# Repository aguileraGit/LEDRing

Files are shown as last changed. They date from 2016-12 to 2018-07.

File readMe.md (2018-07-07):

## Update
As best as I can remember, the mold needs to be solid. The silicon-ish material didn't stick well. And apparently I've decided to add a motor driver. I think the PCB is all working (v1.2). I really want to change out the LEDs so they're cheaper.

## READ ME
LED Ring (needs a better name) is an Arduino based platform. It contains a ring of LEDs, accelerometer, Atmel 328p, FTDI, USB (IP68), and debug LED. In the future the device will be encased in silicon-ish type material making the device IP68. Yes, you'll be able to dunk it in water.

## Hardware
A few minor updates need to be done to the HW. Mainly a capacitor to keep the FTDI from resetting and preventing uploads from Arduino IDE. I think there's a capacitor that needs a different footprint.

## Software
Current SW is interruptTest.ino. I really need to create a library to hide a lot of stuff (define DEBUG_LED for example).

Thanks to all who have created libraries and saved me countless hours. Mainly MMA8452 and NeoPixels!

## Mold
Four part mold. Two parts create the mold. The third holds a magnet that interns holds the PCB steady while pouring the silicon. The forth part contains a "nub" to prevent the PCB from wiggling around. This is meant to be printed at 0.1mm resolution. It needs to be glued on to the rest of the mold. The rest of the parts can be printed at 0.2mm.
- Bluesil V-249A/B.
- Hardness: 67A (Fitbit band has a hardness of 60)
- https://www.freemansupply.com/products/mold-making-silicone-rubber/bluestar-addition-cure-silicone-rubber/v-249-mold-making-silicone-rubber-heat-cure
 - Need to upload the 3d mold models.
 - Need to upload print settings.

#### Old references - Might not even be using some of these.
https://github.com/MajenkoLibraries/Average
https://github.com/rocketscream/Low-Power
https://github.com/adafruit/Adafruit_NeoPixel
https://github.com/akupila/Arduino-MMA8452

#### Or these
http://www.engblaze.com/hush-little-microprocessor-avr-and-arduino-sleep-mode-basics/
http://rubenlaguna.com/wp/2008/10/15/arduino-sleep-mode-waking-up-when-receiving-data-on-the-usart/
https://www.arduino.cc/en/Tutorial/SerialEvent
http://donalmorrissey.blogspot.com/2011/11/sleeping-arduino-part-4-wake-up-via.html

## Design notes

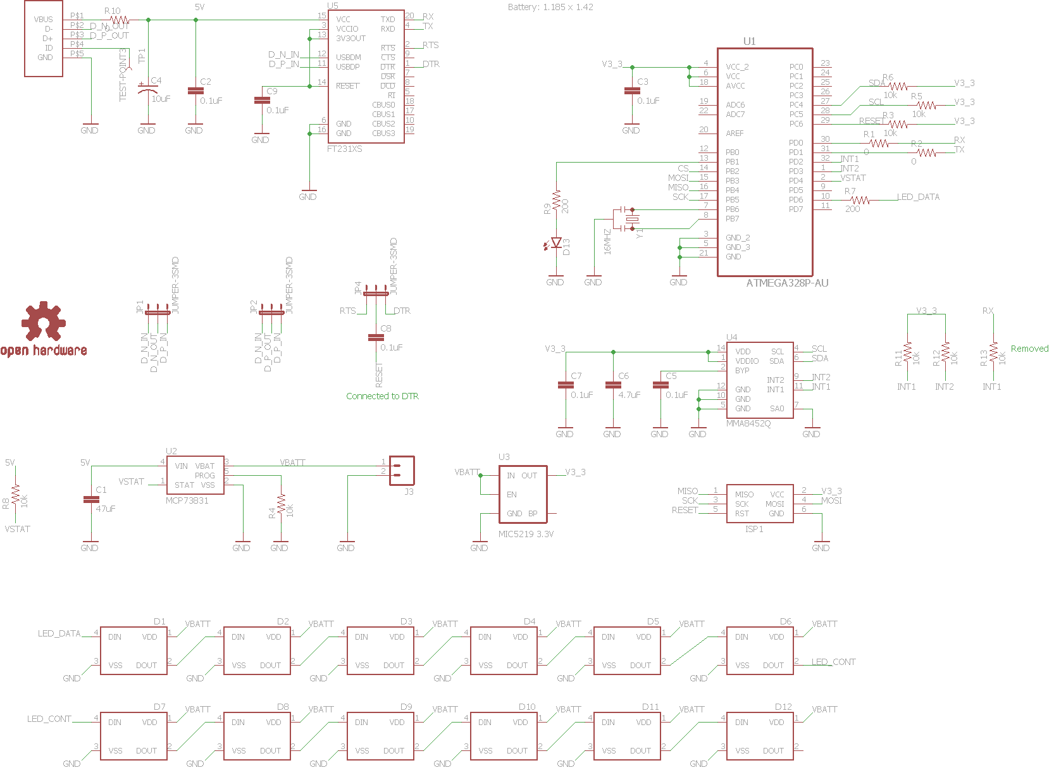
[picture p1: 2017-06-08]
ledRing.png

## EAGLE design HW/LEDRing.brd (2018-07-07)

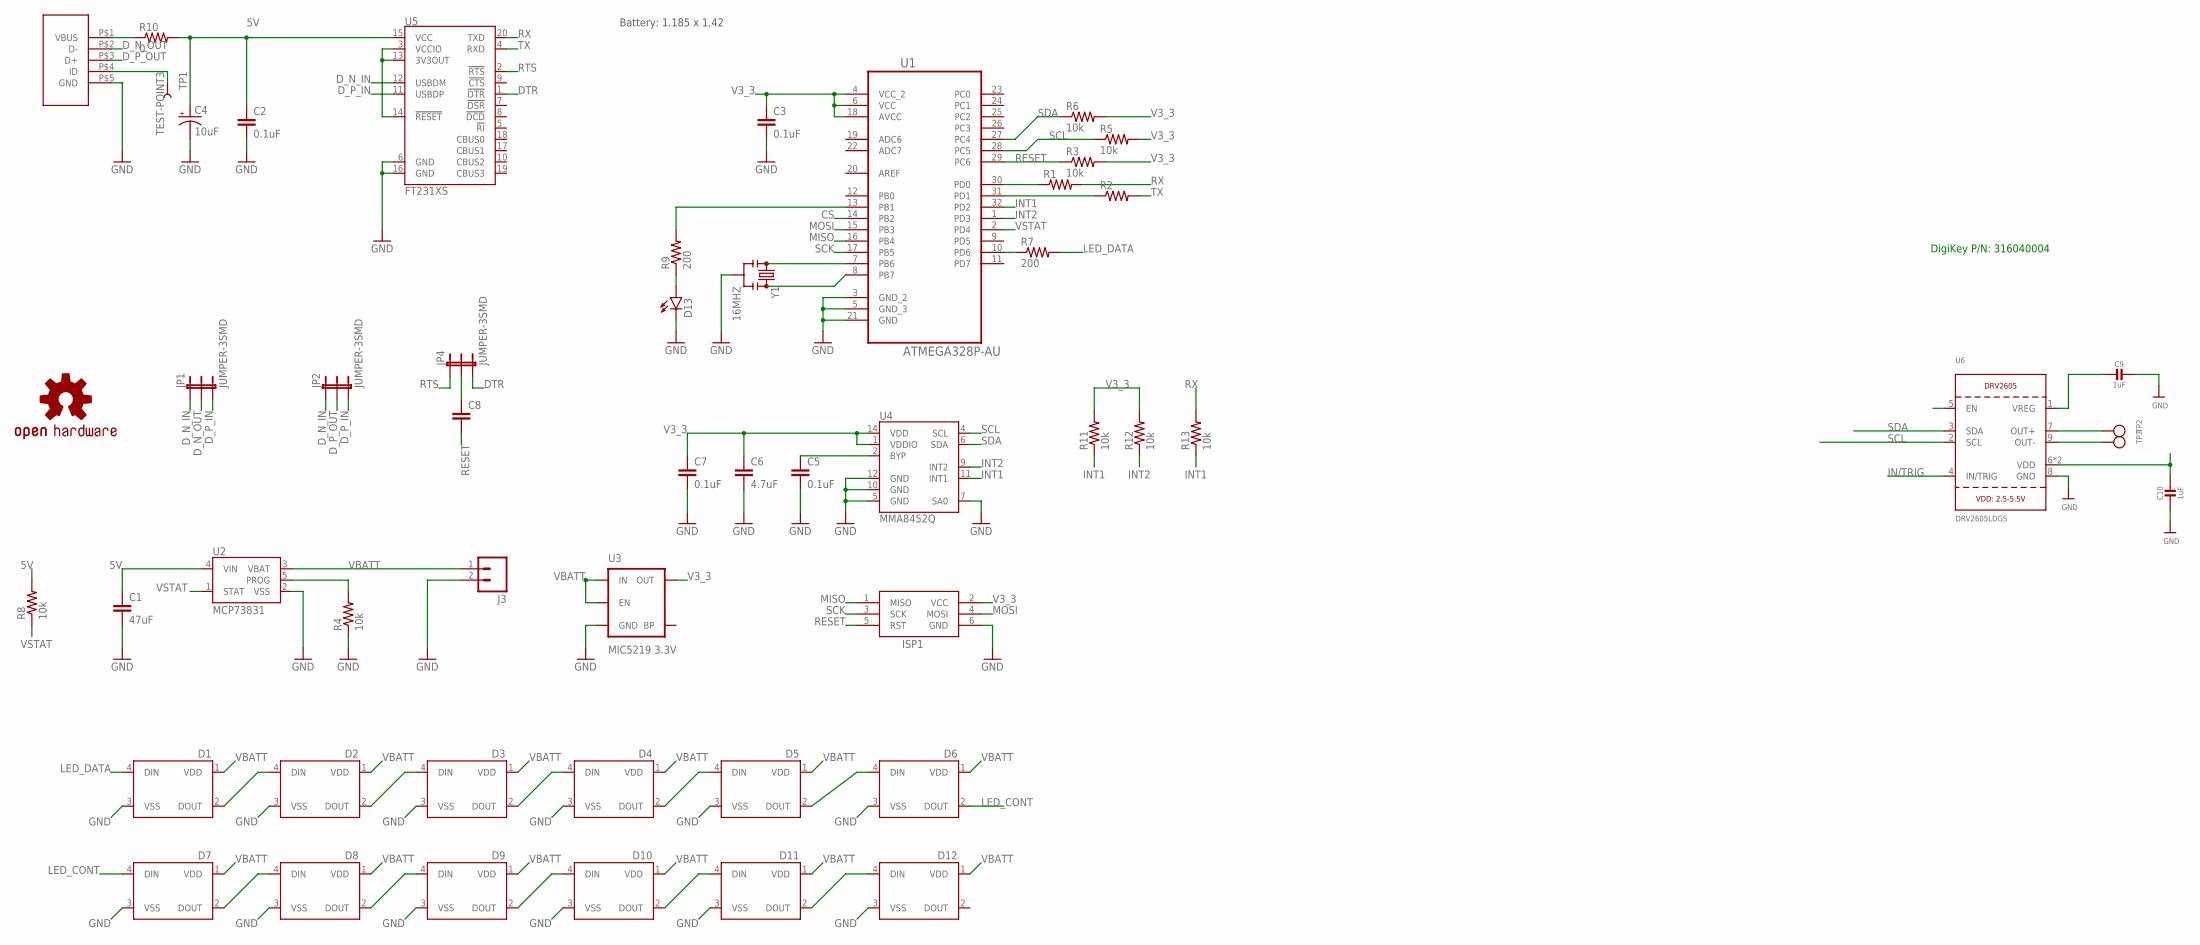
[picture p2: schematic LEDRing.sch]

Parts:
C1: 47uF; 0603-CAP
C2, C3, C5, C7: 0.1uF; 0603-CAP
C4: 10uF; 0603-POL
C6: 4.7uF; 0603-CAP
C8: CAP0603-CAP; 0603-CAP
C9, C10: 1uF; 0805-NO
D1, D2, D3, D4, D5, D6, D7, D8, D9, D10, D11, D12: WS2812B
D13: LED0603; LED-0603
ISP1: AVRISP-BOX
J3: M02PTH; 1X02
JP1, JP2, JP4: JUMPER-3SMD; SJ_3
LOGO1: OSHW-LOGOMINI; OSHW-LOGO-MINI
R1, R2: RESISTOR0603-RES; 0603-RES
R3, R4, R5, R6, R8, R11, R12, R13: 10k; 0603-RES
R7, R9: 200; 0603-RES
R10: 0; 0603-RES
TP1: TEST-POINT3; PAD.03X.03
TP2, TP3: TESTPOINTPAD2MM; TESTPOINT_PAD_2MM
U1: ATMEGA328P-AU; QFP80P900X900X120-32N
U2: MCP73831; SOT23-5
U3: MIC5219 3.3V; SOT23-5
U4: MMA8452Q; QFN-16_0.5MM
U5: FT231XS; SSOP20_L
U6: DRV2605LDGS; PSOP10
U$1: TE_USB_A121025CT
Y1: 16MHZ; RESONATOR-SMD

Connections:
5V: C1.1, C2.1, C4.A (+), R8.2, R10.2, U2.4 (VIN), U5.15 (VCC)
CS: U1.14 (PB2)
DTR: JP4.3, U5.1 (!DTR)
D_N_IN: JP1.1, JP2.1, U5.12 (USBDM)
D_N_OUT: JP1.2, U$1.P$2 (D-)
D_P_IN: JP1.3, JP2.3, U5.11 (USBDP)
D_P_OUT: JP2.2, U$1.P$3 (D+)
GND: C1.2, C2.2, C3.2, C4.K (-), C5.2, C6.2, C7.2, C9.1, C10.2, D1.3 (VSS), D2.3 (VSS), D3.3 (VSS), D4.3 (VSS), D5.3 (VSS), D6.3 (VSS), D7.3 (VSS), D8.3 (VSS), D9.3 (VSS), D10.3 (VSS), D11.3 (VSS), D12.3 (VSS), D13.C, ISP1.6 (GND), J3.2, R4.1, U1.3 (GND_2), U1.5 (GND_3), U1.21 (GND), U2.2 (VSS), U3.2 (GND), U4.5 (GND), U4.7 (SA0), U4.10 (GND), U4.12 (GND), U5.6 (GND), U5.16 (GND), U6.8 (GND), U$1.P$5 (GND), Y1.2
IN/TRIG: U6.4 (IN/TRIG)
INT1: R11.1, R13.1, U1.32 (PD2), U4.11 (INT1)
INT2: R12.1, U1.1 (PD3), U4.9 (INT2)
LED_CONT: D6.2 (DOUT), D7.4 (DIN)
LED_DATA: D1.4 (DIN), R7.2
MISO: ISP1.1 (MISO), U1.16 (PB4)
MOSI: ISP1.4 (MOSI), U1.15 (PB3)
unnamed: R1.1, U1.30 (PD0)
unnamed: R2.1, U1.31 (PD1)
unnamed: C5.1, U4.2 (BYP)
unnamed: R10.1, U$1.P$1 (VBUS)
unnamed: U5.3 (VCCIO), U5.13 (3V3OUT), U5.14 (!RESET)
unnamed: U1.8 (PB7), Y1.3
unnamed: U1.7 (PB6), Y1.1
unnamed: R4.2, U2.5 (PROG)
unnamed: R7.1, U1.10 (PD6)
unnamed: D1.2 (DOUT), D2.4 (DIN)
unnamed: D2.2 (DOUT), D3.4 (DIN)
unnamed: D3.2 (DOUT), D4.4 (DIN)
unnamed: D4.2 (DOUT), D5.4 (DIN)
unnamed: D5.2 (DOUT), D6.4 (DIN)
unnamed: D7.2 (DOUT), D8.4 (DIN)
unnamed: D8.2 (DOUT), D9.4 (DIN)
unnamed: D9.2 (DOUT), D10.4 (DIN)
unnamed: D10.2 (DOUT), D11.4 (DIN)
unnamed: D11.2 (DOUT), D12.4 (DIN)
unnamed: C9.2, U6.1 (VREG)
unnamed: R9.2, U1.13 (PB1)
unnamed: D13.A, R9.1
unnamed: TP1.P$1, U$1.P$4 (ID)
unnamed: C10.1, U6.6 (VDD), U6.10 (VDD)
OUT+: TP2.P$1, U6.7 (OUT+)
OUT-: TP3.P$1, U6.9 (OUT-)
RESET: C8.2, ISP1.5 (RST), R3.1, U1.29 (PC6)
RTS: JP4.1, U5.2 (!RTS)
RTS_OR_DTR: C8.1, JP4.2
RX: R1.2, R13.2, U5.20 (TXD)
SCK: ISP1.3 (SCK), U1.17 (PB5)
SCL: R5.1, U1.28 (PC5), U4.4 (SCL), U6.2 (SCL)
SDA: R6.1, U1.27 (PC4), U4.6 (SDA), U6.3 (SDA)
TX: R2.2, U5.4 (RXD)
V3_3: C3.1, C6.1, C7.1, ISP1.2 (VCC), R3.2, R5.2, R6.2, R11.2, R12.2, U1.4 (VCC_2), U1.6 (VCC), U1.18 (AVCC), U3.5 (OUT), U4.1 (VDDIO), U4.14 (VDD)
VBATT: D1.1 (VDD), D2.1 (VDD), D3.1 (VDD), D4.1 (VDD), D5.1 (VDD), D6.1 (VDD), D7.1 (VDD), D8.1 (VDD), D9.1 (VDD), D10.1 (VDD), D11.1 (VDD), D12.1 (VDD), J3.1, U2.3 (VBAT), U3.1 (IN), U3.3 (EN)
VSTAT: R8.1, U1.2 (PD4), U2.1 (STAT)

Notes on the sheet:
Battery: 1.185 x 1.42
DigiKey P/N: 316040004

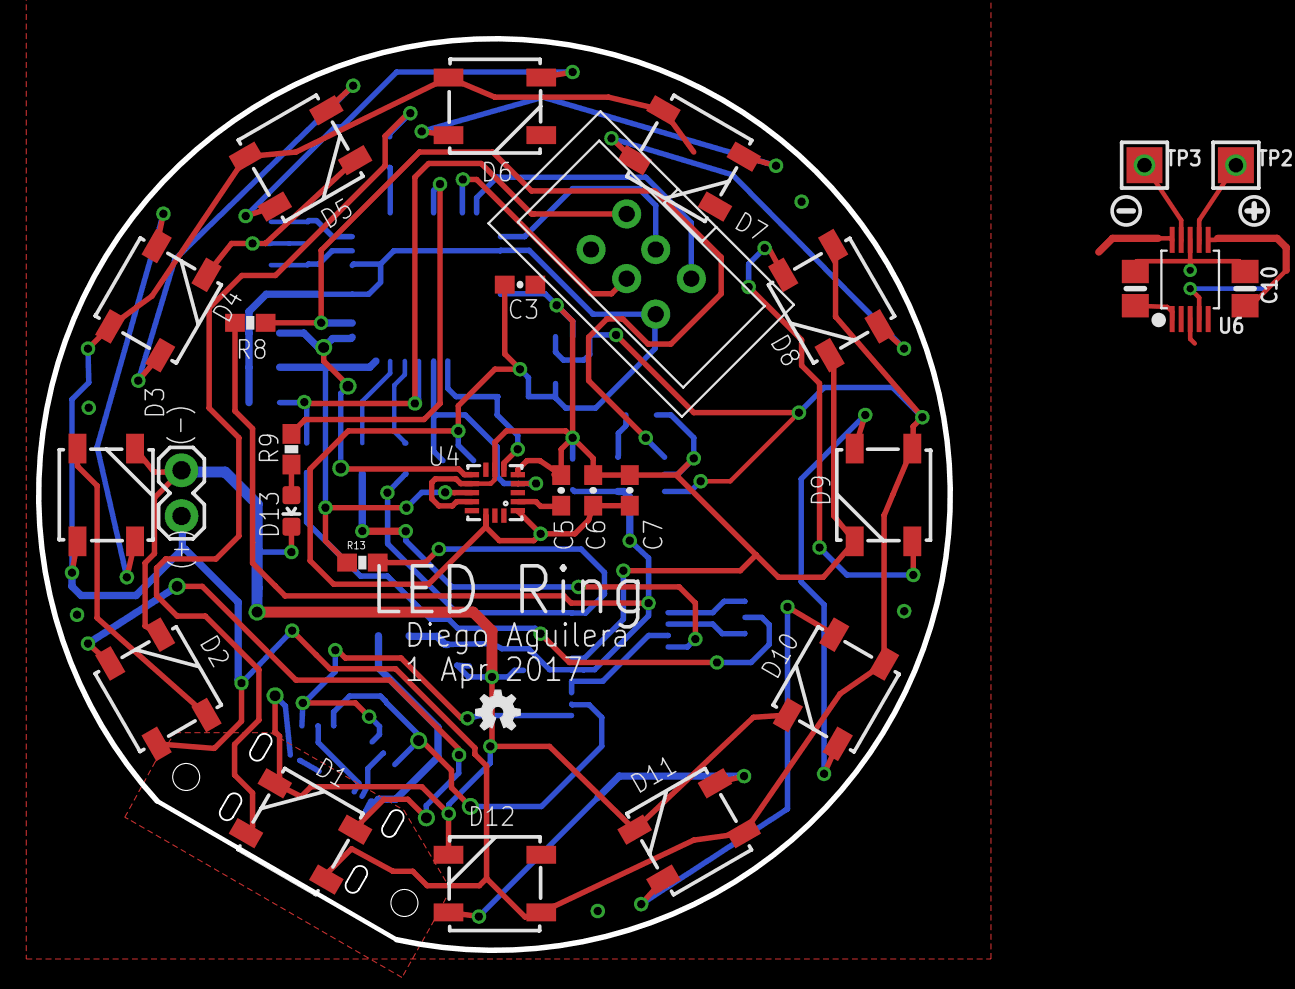
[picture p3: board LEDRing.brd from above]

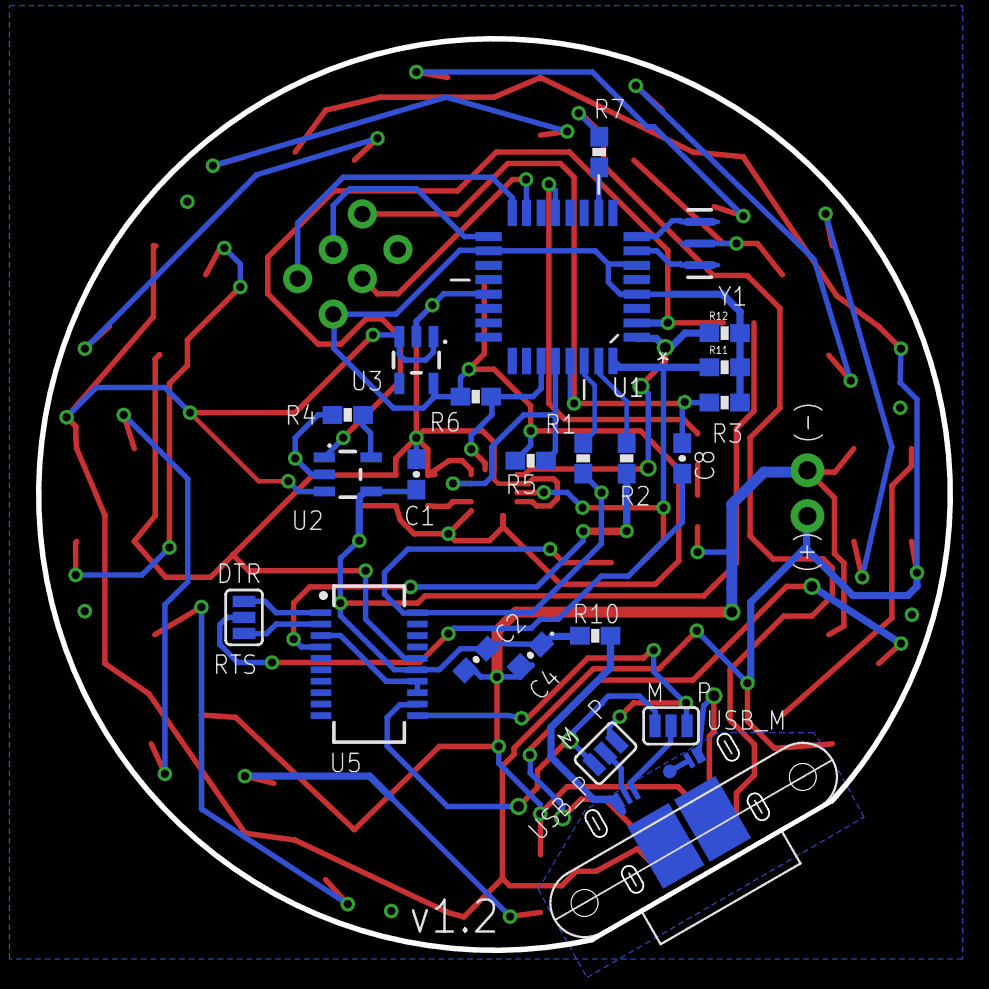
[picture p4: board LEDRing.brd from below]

Board: 2 copper layers, 50.6 x 50.6 mm, 55 parts (24 on the bottom side), 50 nets.

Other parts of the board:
U$5: SYMBOL_PLUS
U$13: SYMBOL_MINUS

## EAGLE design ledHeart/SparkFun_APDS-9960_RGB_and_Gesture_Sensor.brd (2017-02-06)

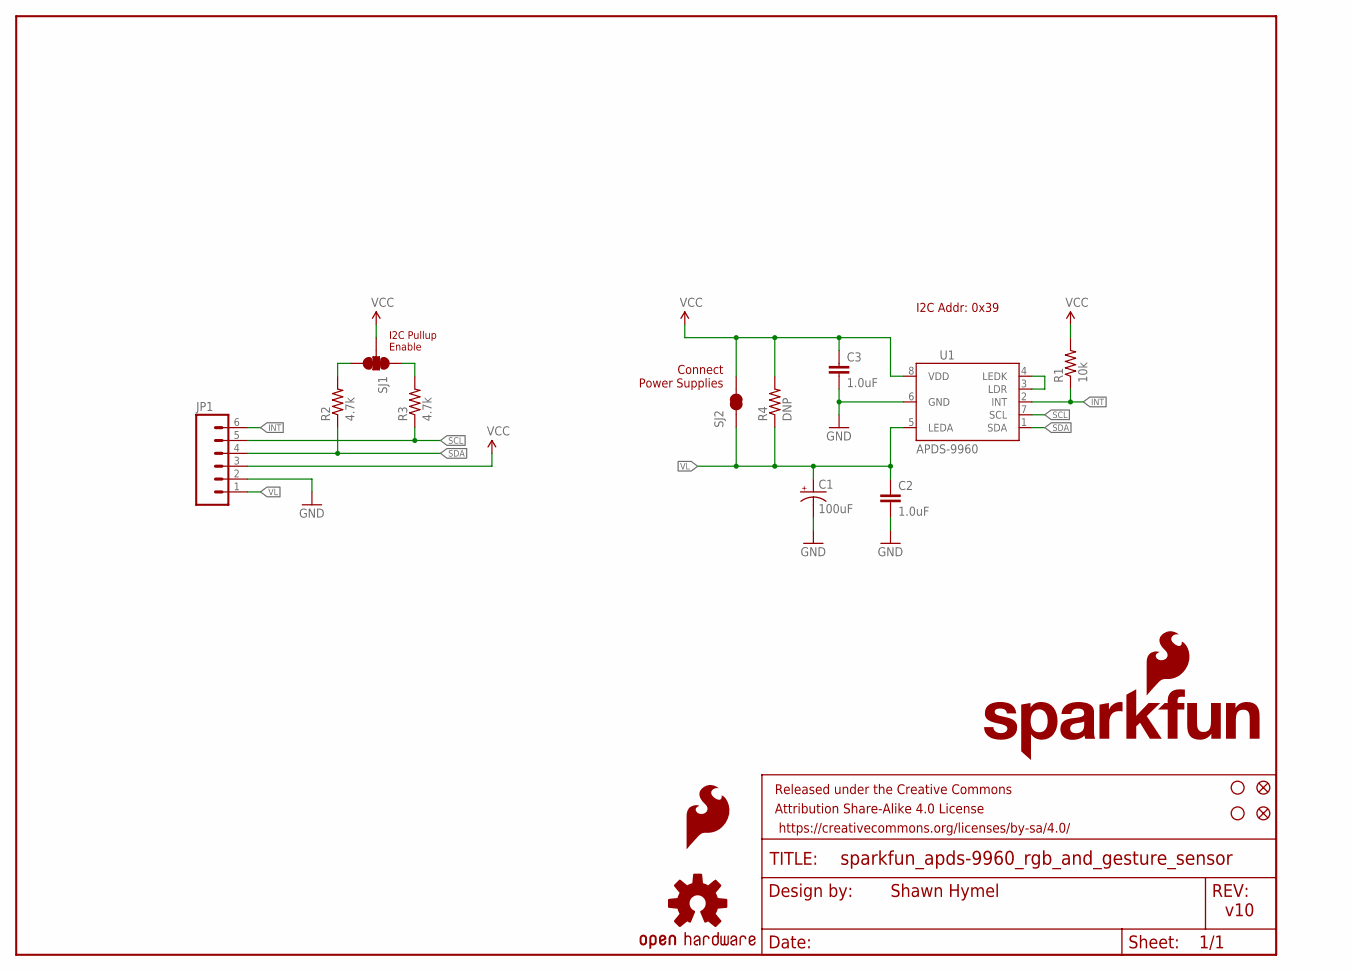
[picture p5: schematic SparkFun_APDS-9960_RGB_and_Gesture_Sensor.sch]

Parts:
C1: 100uF; EIA7343
C2, C3: 1.0uF; 0603-CAP
FID1, FID2: FIDUCIAL1X2; FIDUCIAL-1X2
FRAME1: FRAME-LETTER; CREATIVE_COMMONS
JP1: M06SIP; 1X06
LOGO1: SFE_LOGO_FLAME.1_INCH; SFE_LOGO_FLAME_.1
LOGO2: OSHW-LOGOS; OSHW-LOGO-S
R1: 10k; 0603-RES
R2, R3: 4.7k; 0603
R4: DNP; 0603-RES
SJ1: SOLDERJUMPER_2WAYPASTE1&2&3; SJ_3_PASTE1&2&3
SJ2: SOLDERJUMPERNC; SJ_2S
STANDOFF1, STANDOFF2: STAND-OFF
U1: APDS-9960
U$1: SFE_LOGO_NAME_FLAME.1_INCH; SFE_LOGO_NAME_FLAME_.1

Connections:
GND: C1.C (-), C2.2, C3.2, JP1.2, U1.6 (GND)
INT: JP1.6, R1.1, U1.2 (INT)
unnamed: R2.2, SJ1.3
unnamed: R3.2, SJ1.1
unnamed: U1.3 (LDR), U1.4 (LEDK)
SCL: JP1.5, R3.1, U1.7 (SCL)
SDA: JP1.4, R2.1, U1.1 (SDA)
VCC: C3.1, JP1.3, R1.2, R4.2, SJ1.2, SJ2.2, U1.8 (VDD)
VL: C1.A (+), C2.1, JP1.1, R4.1, SJ2.1, U1.5 (LEDA)

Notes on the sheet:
v10
Shawn Hymel
I2C Addr: 0x39
I2C Pullup Enable
Connect Power Supplies

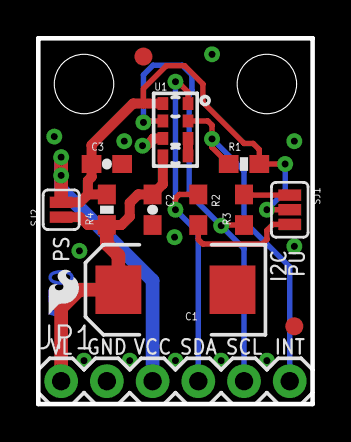
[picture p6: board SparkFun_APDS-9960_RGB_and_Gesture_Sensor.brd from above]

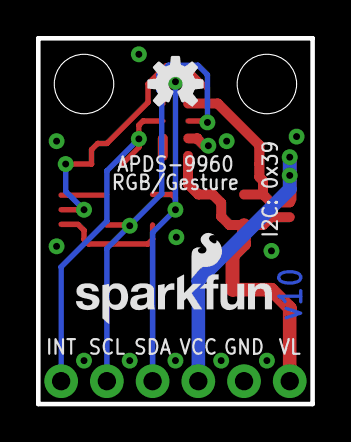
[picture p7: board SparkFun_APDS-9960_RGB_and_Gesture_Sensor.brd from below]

Board: 2 copper layers, 15.2 x 20.3 mm, 19 parts (2 on the bottom side), 9 nets.

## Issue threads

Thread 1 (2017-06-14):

Try this

aguileraGit, 2017-06-14:
#include <TimerOne.h>
#include <Wire.h>
#include <MMA8452.h>
#include <MMA8452Reg.h>
#include <Adafruit_NeoPixel.h>
#include <LowPower.h>
#include <avr/power.h>

https://www.amazon.com/Inkbird-Temperature-ITC-100VH-40A-SSR/dp/B00ADHNSGI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

//Debug LED
#define DEBUG_LED  9

//NeoPixels
#define PIXEL_PIN  6
#define PIXEL_COUNT 12

//System
MMA8452 accelerometer;
Adafruit_NeoPixel strip = Adafruit_NeoPixel(PIXEL_COUNT, PIXEL_PIN, NEO_GRB);
volatile bool interrupt;
unsigned long timerCount;
#define SHUTDOWN  5000  //Shutdown - 1000ms = 1s

//App specific Led
volatile bool updateBlinkLed;
volatile bool ledBlink;
volatile bool updateAllLeds;
volatile int updateAllCount;
volatile int currentPixel;

volatile int ledNumAtTap;

volatile int ledNum;
volatile int randLed;

//Sleep
bool sleepEnabled;
bool sleepingZZZ;
bool activity;
unsigned long activityCount;

void setup() {
  //Enable Debug LED
  pinMode(DEBUG_LED, OUTPUT);

  //Start i2c (Wire) for accelerometer
  Wire.begin();

  bool initialized = accelerometer.init();

  if (initialized) {
    accelerometer.setDataRate(MMA_400hz);
    accelerometer.setRange(MMA_RANGE_2G);

    accelerometer.enableSingleTapDetector(MMA_X + MMA_Y + MMA_Z);
    accelerometer.enableDoubleTapDetector(MMA_X + MMA_Y + MMA_Z, 0x33, 0xBB);
    accelerometer.setTapThreshold(0x20, 0x20, 0x20);

    accelerometer.setInterruptsEnabled(MMA_TAP);
    accelerometer.configureInterrupts(false, false);
    accelerometer.setInterruptPins(false, false, false, true, false, false);

    attachInterrupt(0, accelerometerInterruptHandler, FALLING);
  }

  //Timer
  Timer1.initialize(1000); //1000ns = 1ms
  Timer1.attachInterrupt(oneMsTimer);

  //Neopixels
  strip.begin();
  strip.show();

  //App specific
  interrupt = false;
  sleepEnabled = true;
  ledBlink = false;
  activity = false;
  activityCount = 0;
  sleepingZZZ = false;

  updateAllCount = 0;
  currentPixel = 0;

  randomSeed(analogRead(0));
  randLed = random(PIXEL_COUNT);
}

void loop() {

  if (!sleepingZZZ) {

    if (interrupt) {
      interrupt = false;

      Timer1.stop();

      bool singleTap, doubleTap;
      bool x, y, z;
      bool negX, negY, negZ;

      //Clear it by reading from it. Duh!
      accelerometer.getTapDetails(&singleTap, &doubleTap, &x, &y, &z, &negX, &negY, &negZ);

      if (singleTap) {
        //Clear all
        for (int j = 0; j < PIXEL_COUNT; j++) {
          strip.setPixelColor(j, strip.Color(0, 0, 0));
          strip.show();
        }

        if (ledNumAtTap == randLed) {
          strip.setPixelColor(ledNumAtTap, strip.Color(0, 32, 0));
          strip.show();
        } else {
          strip.setPixelColor(ledNumAtTap, strip.Color(32, 0, 0));
          strip.show();
        }

        delay(800);
      }

      //Get new random LED
      randLed = random(PIXEL_COUNT);

    //Resume interrupt and timer operations
    Timer1.resume();

    } //End interrupt

    if (updateBlinkLed) {
      Timer1.stop();
      ledBlink = !ledBlink;

      //Clear all
      for (int j = 0; j < PIXEL_COUNT; j++) {
        strip.setPixelColor(j, strip.Color(0, 0, 0));
        strip.show();
      }

      for (int i = 0; i < PIXEL_COUNT; i++) {
        if (i == currentPixel) {
          strip.setPixelColor(currentPixel, strip.Color(16, 16, 16));
        } else if (i == randLed) {
          if (ledBlink) {
            strip.setPixelColor(randLed, strip.Color(0, 0, 32));
          } else {
            strip.setPixelColor(randLed, strip.Color(0, 0, 0));
          }
        } else {
          strip.setPixelColor(i, strip.Color(0, 0, 0));
        }
        strip.show();
      }

      //Blinking on the target LED is faster than the other LEDs - Control the rate of all the LEDs here.
      updateAllCount++;
      if (updateAllCount >= 2) {
        updateAllCount = 0;

        currentPixel++;

        if (currentPixel >= PIXEL_COUNT) {
          currentPixel = 0;
        }

      }

      updateBlinkLed = false;
      Timer1.resume();
    }

    //Sleep - power savings
    if (sleepEnabled) {
      sleepFn();
    }

  }//Sleeping

}

void accelerometerInterruptHandler() {
  interrupt = true;
  activity = true;
  ledNumAtTap = currentPixel;
  //sleepingZZZ = false;
}

void oneMsTimer() {

  //Update every 1ms
  timerCount++;

  //Update every 100ms
  if (timerCount % 100 == 0) {
    ;
  }

  //Update every 50ms
  if (timerCount % 20 == 0) {
    updateBlinkLed = true;
  }

  //-------- Track no activity --------//

  /*if (activity == false) {
    activityCount++;
  } else {
    activityCount = 0;
    activity = false;
  }
  */

  //-------- Shut Down --------//
  if (activityCount == SHUTDOWN) {
    activityCount = 0;

    //Turn off Debug LED
    //digitalWrite(DEBUG_LED, HIGH);

    //Turn off Pixels
    for (int j = 0; j < PIXEL_COUNT; j++) {
      strip.setPixelColor(j, strip.Color(0, 0, 0));
      strip.show();
    }

    //sleepingZZZ = true;
    //Call sleep function.
    //while (sleepingZZZ) {
    //sleepFn();
    //}

  }
}

void sleepFn() {
  LowPower.idle(SLEEP_15MS, ADC_OFF, TIMER2_OFF, TIMER1_ON, TIMER0_OFF, SPI_OFF, USART0_ON, TWI_ON);
}

Closed 2017-06-16.

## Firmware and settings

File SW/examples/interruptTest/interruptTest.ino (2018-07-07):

#include <TimerOne.h>
#include <Wire.h>
#include <MMA8452.h>
#include <MMA8452Reg.h>
#include <Adafruit_NeoPixel.h>
#include <LowPower.h>
#include <avr/power.h>

//Debug LED
#define DEBUG_LED  9

//NeoPixels
#define PIXEL_PIN  6
#define PIXEL_COUNT 12

//System
MMA8452 accelerometer;
Adafruit_NeoPixel strip = Adafruit_NeoPixel(PIXEL_COUNT, PIXEL_PIN, NEO_GRB);
volatile bool interrupt;
unsigned long timerCount;
#define SHUTDOWN  30000  //Shutdown - 1000ms = 1s
volatile bool shutDown;

//App specific Led
volatile bool updateBlinkLed;
volatile bool ledBlink;
volatile bool updateAllLeds;
volatile int updateAllCount;
volatile int currentPixel;

volatile int ledNumAtTap;
volatile int ledNum;
volatile int randLed;

#define GAME_SPEED_SLOW  80 
#define GAME_SPEED_FAST  20
#define GAME_SPEED       GAME_SPEED_SLOW

//Sleep
bool sleepEnabled;
bool activity;
unsigned long activityCount;


void setup() {
  
  //Enable Debug LED
  pinMode(DEBUG_LED, OUTPUT);

  //Start i2c (Wire) for accelerometer
  Wire.begin();

  bool initialized = accelerometer.init();

  if (initialized) {
    accelerometer.setDataRate(MMA_400hz);
    accelerometer.setRange(MMA_RANGE_2G);

    accelerometer.enableSingleTapDetector(MMA_X + MMA_Y + MMA_Z);
    accelerometer.enableDoubleTapDetector(MMA_X + MMA_Y + MMA_Z, 0x33, 0xBB);
    accelerometer.setTapThreshold(0x20, 0x20, 0x20);

    accelerometer.setInterruptsEnabled(MMA_TAP);
    accelerometer.configureInterrupts(false, false);
    accelerometer.setInterruptPins(false, false, false, true, false, false);

    attachInterrupt(0, accelerometerInterruptHandler, FALLING);
  }

  //Timer
  Timer1.initialize(1000); //1000ns = 1ms
  Timer1.attachInterrupt(oneMsTimer);

  //Neopixels
  strip.begin();
  strip.show();

  //App specific
  interrupt = false;
  sleepEnabled = true;
  ledBlink = false;
  activity = false;
  activityCount = 0;
  shutDown = false;

  updateAllCount = 0;
  currentPixel = 0;

  randomSeed(analogRead(0));
  randLed = random(PIXEL_COUNT);
}

void loop() {
  
  /********************************************************/
  // Deal with taps
  /********************************************************/
  if (interrupt) {
    interrupt = false;

    Timer1.stop();

    bool singleTap, doubleTap;
    bool x, y, z;
    bool negX, negY, negZ;

    //Clear it by reading from it. Duh!
    accelerometer.getTapDetails(&singleTap, &doubleTap, &x, &y, &z, &negX, &negY, &negZ);

    if (singleTap) {
      //Clear all
      for (int j = 0; j < PIXEL_COUNT; j++) {
        strip.setPixelColor(j, strip.Color(0, 0, 0));
        strip.show();
      }

      if (ledNumAtTap == randLed) {
        strip.setPixelColor(ledNumAtTap, strip.Color(0, 32, 0));
        strip.show();
      } else {
        strip.setPixelColor(ledNumAtTap, strip.Color(32, 0, 0));
        strip.show();
      }

      delay(800);
    }

    //Get new random LED
    randLed = random(PIXEL_COUNT);

    //Resume interrupt and timer operations
    Timer1.resume();

  } //End interrupt

  /********************************************************/
  // Set LEDs
  /********************************************************/
  if (updateBlinkLed) {
    Timer1.stop();
    ledBlink = !ledBlink;

    //Clear all
    for (int j = 0; j < PIXEL_COUNT; j++) {
      strip.setPixelColor(j, strip.Color(0, 0, 0));
      strip.show();
    }

    for (int i = 0; i < PIXEL_COUNT; i++) {
      if (i == currentPixel) {
        strip.setPixelColor(currentPixel, strip.Color(16, 16, 16));
      } else if (i == randLed) {
        if (ledBlink) {
          strip.setPixelColor(randLed, strip.Color(0, 0, 32));
        } else {
          strip.setPixelColor(randLed, strip.Color(0, 0, 0));
        }
      } else {
        strip.setPixelColor(i, strip.Color(0, 0, 0));
      }
      strip.show();
    }

    //Blinking on the target LED is faster than the other LEDs - Control the rate of all the LEDs here.
    updateAllCount++;
    if (updateAllCount >= 2) {
      updateAllCount = 0;

      currentPixel++;

      if (currentPixel >= PIXEL_COUNT) {
        currentPixel = 0;
      }

    }

    updateBlinkLed = false;
    Timer1.resume();
  }


  /********************************************************/
  // Sleep for a few milliseconds
  /********************************************************/
  if (sleepEnabled) {
    sleepFn();
  }

  /********************************************************/
  // Shut device down until a tap occurrs
  /********************************************************/
  if (shutDown) {

    digitalWrite(DEBUG_LED, LOW);

    for (int j = 0; j < PIXEL_COUNT; j++) {
      strip.setPixelColor(j, strip.Color(0, 0, 0));
      strip.show();
    }
    
    //Wait for tap
    while (!activity) {
      sleepFn();
    }

    activityCount = 0;
    shutDown = false;
  }

}




void accelerometerInterruptHandler() {
  interrupt = true;
  activity = true;
  ledNumAtTap = currentPixel;
}



void oneMsTimer() {
  /********************************************************/
  // Update every 1ms
  /********************************************************/
  timerCount++;

  /********************************************************/
  // Update every 50ms
  /********************************************************/
  if (timerCount % GAME_SPEED == 0) {
    updateBlinkLed = true;
  }

  /********************************************************/
  // Track activity
  /********************************************************/
  if (!activity) {
    activityCount++;
  } else {
    activityCount = 0;
    activity = false;
  }

  /********************************************************/
  // Shut down
  /********************************************************/
  if (activityCount == SHUTDOWN) {
    shutDown = true;
  }
}


void sleepFn() {
  LowPower.idle(SLEEP_15MS, ADC_OFF, TIMER2_OFF, TIMER1_ON, TIMER0_OFF, SPI_OFF, USART0_ON, TWI_ON);
}

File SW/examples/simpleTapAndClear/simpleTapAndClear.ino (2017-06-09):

#include <Average.h>
#include <LowPower.h>
#include <Wire.h>
#include <MMA8452.h>
#include <MMA8452Reg.h>
#include <Adafruit_NeoPixel.h>
#include <avr/power.h>

/*
Select Arduino Pro or Pro Mini AND
328P 3.3V 8Mhz from Processor
Burn bootloader with 16Mhz

https://github.com/MajenkoLibraries/Average
https://github.com/rocketscream/Low-Power
https://github.com/adafruit/Adafruit_NeoPixel
https://github.com/akupila/Arduino-MMA8452
*/

//Debug LED
#define DEBUG_LED  9

//NeoPixels
#define PIXEL_PIN  6
#define PIXEL_COUNT 12

MMA8452 accelerometer;
Adafruit_NeoPixel strip = Adafruit_NeoPixel(PIXEL_COUNT, PIXEL_PIN, NEO_GRB);

//Program specific
int rVal = 1;
int gVal = 1;
int bVal = 1;

enum progStates {
  R_STATE,
  B_STATE,
  G_STATE,
  RESET,
  SLEEP_STATE
};
enum progStates PROGSTATE;

bool fakeSleep;
int restoreR, restoreG, restoreB;

//Low Pass filter - Hopefully cuts down on the random "Sleep"
#define AVG_LENGTH  125
Average<float> ave(AVG_LENGTH);
#define AVG_THRESHOLD  -0.7

void setup() {
  //Enable Debug LED
  pinMode(DEBUG_LED, OUTPUT);

  //Start i2c (Wire) for accelerometer
  Wire.begin();

  bool initialized = accelerometer.init();
  if (initialized) {
    accelerometer.setDataRate(MMA_800hz);  // we need a quick sampling rate
    accelerometer.setRange(MMA_RANGE_2G);

    accelerometer.enableSingleTapDetector(MMA_X + MMA_Y + MMA_Z);
    accelerometer.enableDoubleTapDetector(MMA_X + MMA_Y + MMA_Z, 0x33, 0xBB);
    accelerometer.setTapThreshold(0x30, 0x30, 0x30);

  } else {
    digitalWrite(DEBUG_LED, HIGH);
    while (true) {};
  }

  //Neopixels
  strip.begin();
  strip.show();

  //Set State
  PROGSTATE = R_STATE;

  //Wake up
  fakeSleep = false;
  
  //Fill Average Array with zero's. -1 is down and +1 is up. Make it swiss.
  for(int j = 0;j<AVG_LENGTH;j++){
    ave.push(0);
  }
}


void loop() {
  
  //Get taps and double taps
  bool singleTap, doubleTap;
  bool x, y, z;
  bool negX, negY, negZ;
  accelerometer.getTapDetails(&singleTap, &doubleTap, &x, &y, &z, &negX, &negY, &negZ);
  
  //Get X value
  float xVal, yVal, zVal;
  accelerometer.getAcceleration(&xVal, &yVal, &zVal);
  
    //Average zVal and decide to sleep
  float currentAverage = ave.rolling(zVal);
  
  //Decide to sleep or wake
  if(currentAverage > AVG_THRESHOLD){
    fakeSleep = false;
  } else {
    //Update LEDs via function
    updateLEDS(0, 0, 0);
    fakeSleep = true;
    PROGSTATE = SLEEP_STATE;
    LowPower.idle(SLEEP_15MS, ADC_OFF, TIMER2_OFF, TIMER1_OFF, TIMER0_OFF, SPI_ON, USART0_OFF, TWI_OFF);
  }
  
  //Select R/G/B state
  if (doubleTap) {
    //digitalWrite(DEBUG_LED, HIGH);

    switch (PROGSTATE) {
      case R_STATE:
        if(fakeSleep == false){
          PROGSTATE = G_STATE;
        }
        break;
      case G_STATE:
        if(fakeSleep == false){
          PROGSTATE = B_STATE;
        }
        break;
      case B_STATE:
        if(fakeSleep == false){
          PROGSTATE = R_STATE;
        }
        break;
      case RESET:
        PROGSTATE = R_STATE;
        break;
      case SLEEP_STATE:
        //LowPower.idle(SLEEP_15MS, ADC_OFF, TIMER2_OFF, TIMER1_OFF, TIMER0_OFF, SPI_OFF, USART0_OFF, TWI_OFF);
        digitalWrite(DEBUG_LED, HIGH);
        break;
      default:
        digitalWrite(DEBUG_LED, HIGH);
        break;
    }
  }//End Double Tap

  //Increase brightness
  if (singleTap) {
    //digitalWrite(DEBUG_LED, LOW);
    
    //Tap detected while sleeping - Time to wake up
    if(PROGSTATE == SLEEP_STATE && fakeSleep == true){
      //digitalWrite(DEBUG_LED, LOW);
      updateLEDS(1, 1, 1);
      PROGSTATE = R_STATE;
    } else {
      //digitalWrite(DEBUG_LED, HIGH);
      //LowPower.idle(SLEEP_15MS, ADC_OFF, TIMER2_OFF, TIMER1_OFF, TIMER0_OFF, SPI_OFF, USART0_OFF, TWI_OFF);
      PROGSTATE = SLEEP_STATE;
    }
  
    if (PROGSTATE == R_STATE && fakeSleep == false) {
      rVal = rVal * 2;
      if (rVal > 255) {
        rVal = 1;
      }

    } else if (PROGSTATE == G_STATE && fakeSleep == false) {
      gVal = gVal * 2;
      if (gVal > 255) {
        gVal = 1;
      }

    } else if (PROGSTATE == B_STATE && fakeSleep == false) {
      bVal = bVal * 2;
      if (bVal > 255) {
        bVal = 1;
      }
    } else {
      //digitalWrite(DEBUG_LED, HIGH);
    }

    //Update LEDs via function
    updateLEDS(rVal, gVal, bVal);

  }//End Single Tap

}//End Main Loop


void updateLEDS(int rUpdate, int gUpdate, int bUpdate) {
  int j = 0;
  for (j = 0; j < PIXEL_COUNT; j++) {
    strip.setPixelColor(j, strip.Color(rUpdate, gUpdate, bUpdate));
    strip.show();
    delay(20);
  }
}

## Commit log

2016-10-12 Init commit
    [LEDRing.brd, LEDRing.sch]
2016-10-14 Added accelerometer Added power Added LEDs
    [LEDRing.brd, LEDRing.sch]
2016-10-20 More updates to layout
    [LEDRing.brd, LEDRing.sch]
2016-10-20 Added script to calculate LED positions
2016-10-20 Updated schematics
    [LEDRing.brd, LEDRing.sch]
2016-10-27 More routing done
    [LEDRing.brd]
2016-11-10 Added USB connector. Needs to be finished. Added python script to help with USB connector layout
2016-11-15 Moved USB connector
    [LEDRing.brd, LEDRing.sch]
2016-11-16 Removed most USB footprint errors
    [LEDRing.brd]
2016-11-16 Moved LEDs so USB fits
    [LEDRing.brd, LEDRing.sch]
2016-11-16 Started tieing LED VSS to GND
    [LEDRing.brd, LEDRing.sch]
2016-11-17 Finished layout. Need to fix text
    [LEDRing.brd, LEDRing.sch]
2016-11-18 Sent board to be made
    [LEDRing.brd, LEDRing.sch]
2016-12-03 Modified folder structure Added Sparkfun and n0m1 libraries Modified library to add tap and double taps! UNFINISHED
    [LEDRing.brd, LEDRing.sch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]
2016-12-16 Updated schematics.
    [LEDRing.brd, LEDRing.sch]
2016-12-16 Removed some files.
    [LEDRing.brd]
2016-12-19 Adding PCB changes for next version.
    [LEDRing.brd, LEDRing.sch]
2017-01-18 Updated to version 1.1.
    [LEDRing.brd, LEDRing.sch]
2017-02-06 Found error for USB part. Fixed. Still need to move usb to original spot.
    [LEDRing.brd, LEDRing.sch]
2017-02-06 Adding LED Heart for the time being.
    [SparkFun_APDS-9960_RGB_and_Gesture_Sensor.brd, SparkFun_APDS-9960_RGB_and_Gesture_Sensor.sch, ledHeart.brd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]
2017-03-02 Moved USB connector.
    [LEDRing.brd, LEDRing.sch]
2017-03-08 Added 0.1uF and 1000uF capacitors. (Need to finish) Added values for components.
    [LEDRing.brd, LEDRing.sch]
2017-03-09 Added a few sample programs.
2017-03-22 Ready for next version? Should probably double check.
    [LEDRing.brd, LEDRing.sch]
2017-03-30 Updated Version
    [LEDRing.brd]
2017-06-08 Uploaded image of schematics
2017-06-09 Adding code examples.
    [BOM.xlsx]
2017-06-12 Added interruptTest
2017-06-13 Quick update before bed.
2017-06-16 Added sleep to interruptTest.ino
2018-07-07 Updating all files. I've started adding a motor driver (vibration motor).
    [BOM.xlsx, LEDRing.brd, LEDRing.sch]

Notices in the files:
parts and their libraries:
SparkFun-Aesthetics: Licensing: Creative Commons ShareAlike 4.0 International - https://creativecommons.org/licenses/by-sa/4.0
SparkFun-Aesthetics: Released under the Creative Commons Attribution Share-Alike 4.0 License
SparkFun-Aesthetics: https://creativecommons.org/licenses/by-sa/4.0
